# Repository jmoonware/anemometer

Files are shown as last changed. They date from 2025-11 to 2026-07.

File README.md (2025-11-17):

# Anemometer Project 
Code for a WiFi sensor and communicator for a [Davis anemometer](https://www.davisinstruments.com/collections/anemometers/products/anemometer-for-vantage-pro2-vantage-pro).

This project uses a Pico W board [RP2040 Pico W](https://www.waveshare.com/raspberry-pi-pico-w.htm) connected to a [Waveshare Pico-Res Touch 3.5 inch touch LCD display](https://www.waveshare.com/wiki/Pico-ResTouch-LCD-3.5) 

The Pico W is ridiculously powerful for a simple WiFi-connected data logger. It can easily service real-time-ish interrupts while communicating over UDP with some other computer (as well as using the I2C bus.)

The electronics are enclosed in a waterproof box with a transparent lid to see the display, powered by a local 5V/3A wall-adapter.

The layout and circuit for the glue board are also included here. There are provisions for I2C devices, a Davis Anemometer, and a 5V servo motor (such as the MG 996R.) There are also a couple of jumpers that can be configured in "debug mode" where the Pico itself simulates the signals that should come from the anemometer (basically, the wind direction 0-3.3 V analog level, and the wind speed reed switch which produces digital pulses at 0 - ~1kHz.)

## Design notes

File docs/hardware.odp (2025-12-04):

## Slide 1

Hole Template

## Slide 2

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
J 14

J 15

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
A B C D E F G H I J K L M N O P Q R S T U V W X Y Z A B

J1: 1,2,3: 5V, NC, GND (Power In)

J2: 1,2,3: 5V, NC, GND (Power Out to Pico)

J3: 1,2: 3.3V, GND (Power from Pico)

J4: 1,2: SCL, SDA (I2C lines from Pico)

J5: 1,2,3,4: 3.3V, SCL, SDA, GND (I2C Bus)

J6, J7 = J5 (I2C Bus)

J8: 1,2,3,4: 3.3V, DIR, GND, SPD (Anemometer, yellow=1)

J9, J10: 1,2: JA, JB (Jumpers, closed in normal ops)

J11: 1,2,3,4: PA1, AGND, PA0,NC (Pico DIR [blu], AGND[grn],SPD[yel])

J12: 1,2,3: PWMIN, JA,JB (Debug; DBG Bl to 1, Jump 2-3 DIR Pico)

J13: 1,2,3: GND, 5V, PWM, PWMIN (Servo; Pin 4 to Debug Black [Pico Pin 9])

J14: 1 GND

J15: 1 PWM (Black wire from Pico Pin 9/D6)

Debug Mode Notes:

Servo PWMIN (Pico Black Pin 9) to J12-1 for debug DIR mode (add jump J12 2-3)

Debug Speed Mode – Remove J9 jumper, Pico White Pin 6 to J9-1

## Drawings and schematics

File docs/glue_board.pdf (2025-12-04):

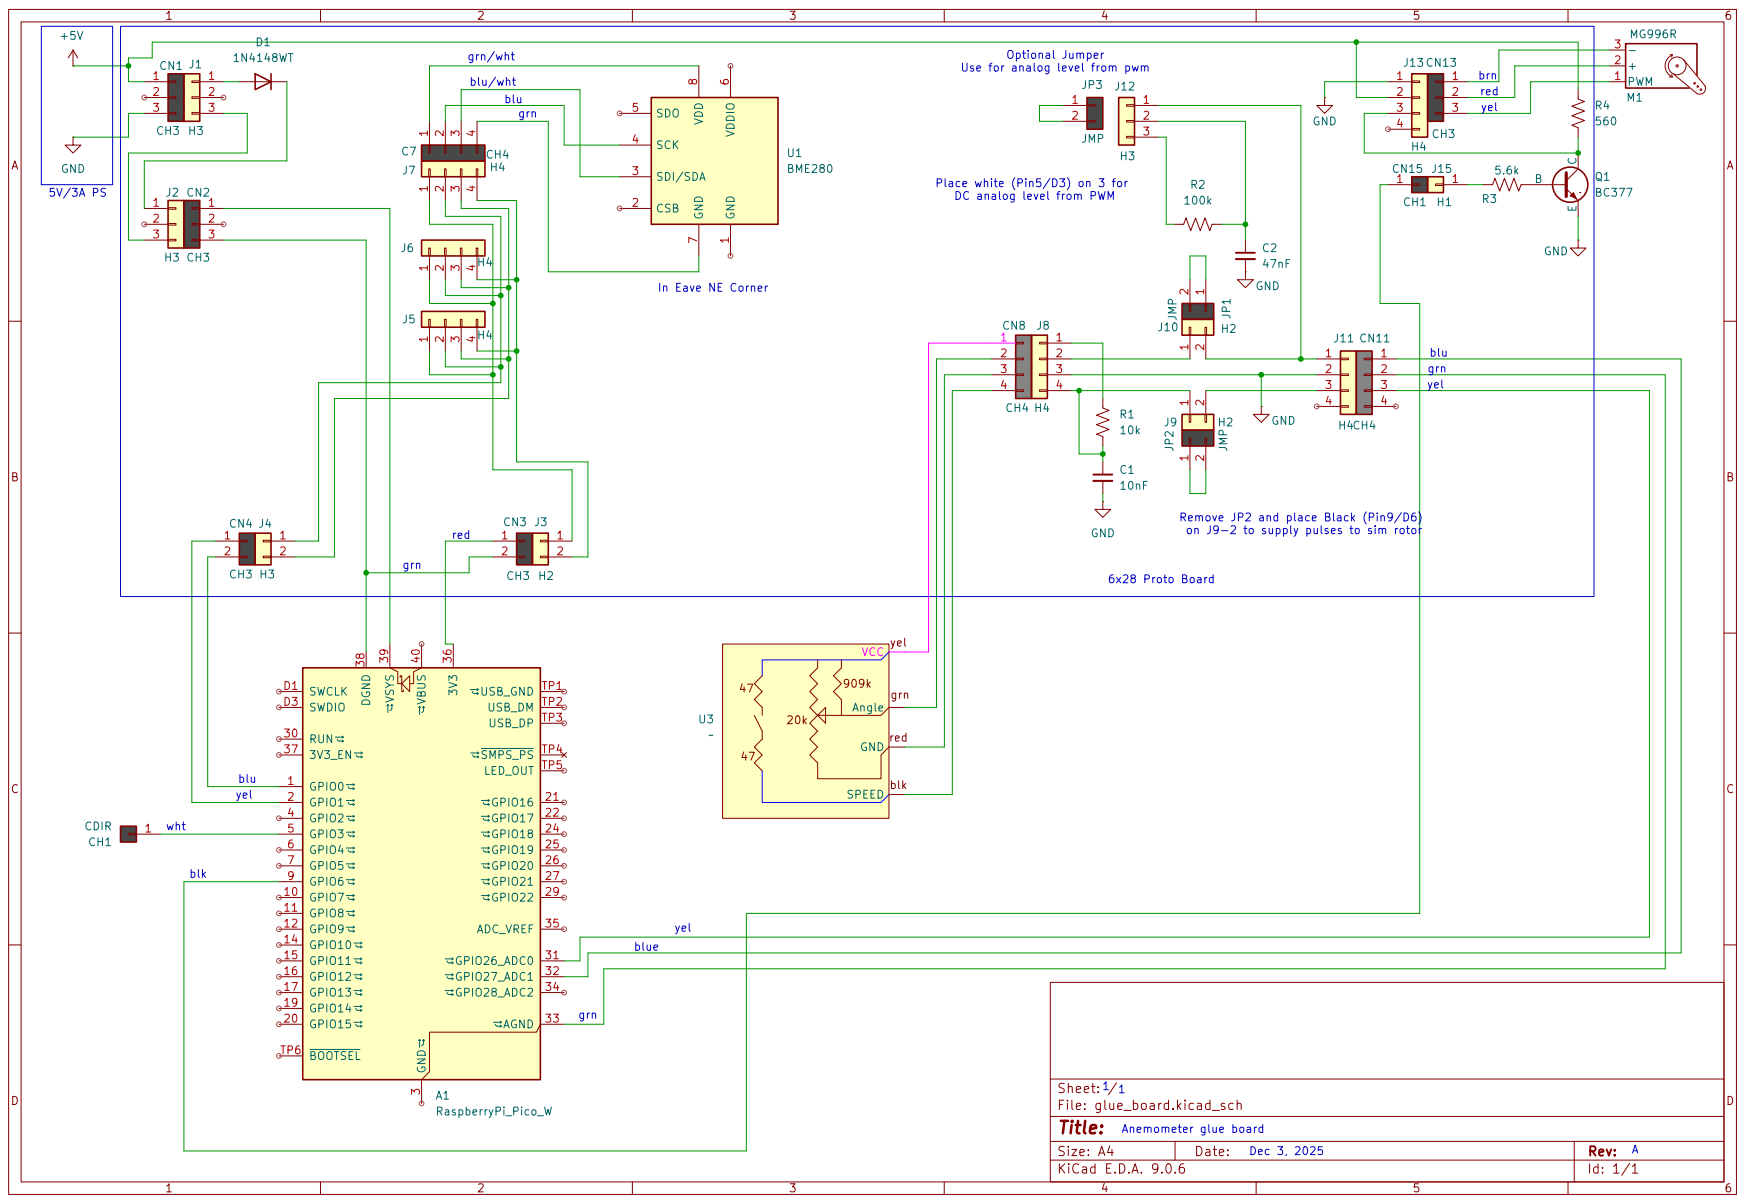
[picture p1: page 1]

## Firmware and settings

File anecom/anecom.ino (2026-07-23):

#include <WiFi.h>
#include <NTPClient.h>
#include <AsyncUDP_RP2040W.h>
#include <Adafruit_BME280.h>
#include <hardware/watchdog.h>

#define WATCHDOG_DELAY_MS 5000

// secret, contains definition of local_ssid, local_pass, and data_url in three lines, literally: 
// char local_ssid[] = "NNN";  //  your network SSID (name)
// char local_pass[] = "PPP";  // your network password
#include "/home/jmoon/Arduino/libraries/local/ssid_harvest.h"
IPAddress static_ip(192,168,1,10);
IPAddress static_dns(192,168,1,2);
IPAddress static_gateway(192,168,1,1);
IPAddress static_subnet(255,255,255,0);

#include <SPI.h>
#include <Adafruit_GFX.h>
#include "Fonts/FreeSerif9pt7b.h"
#include "Fonts/FreeMonoBold9pt7b.h"
#include "Fonts/FreeMonoBold24pt7b.h"
#include "Fonts/FreeMonoBold18pt7b.h"
#include "Fonts/FreeMonoBold12pt7b.h"
#include <TFT_eSPI.h>
#include <hardware/pwm.h>
#include <elapsedMillis.h>

#include <Wire.h>

#include "src/DateTimeNTP/DateTimeNTP.h"
#include "src/windcal.h"

#define VERSION_STRLEN 9
char version[] = "202607221";

// Backlight update = 133 MHz/(255*2360) = 221 Hz
#define BACKLIGHT_DIV 255
#define BACKLIGHT_TOP 2360
TFT_eSPI tft = TFT_eSPI();
uint8_t backlight_pwm_slice;

// here "physical pin" means pins 1-40 of the Pico W board
#define DEBUG_DIR_PWM_PIN D6 // physical pin 9, black wire, also motor PWM
#define DEBUG_SPEED_PWM_PIN D4 // physical pin 6
#define DEBUG_SPEED_ISR_PIN D3 // physical pin 5, white wire
// 133/(522*255) ==> 1.0008 ms per interrupt
#define DEBUG_SPEED_ISR_TOP 522 // clock cycles (possibly pre-divided) to generate IRQ
#define DEBUG_SPEED_ISR_CLK_DIV 255 // pre-divide 133 MHz clock by this
#define DEBUG_DAC_TOP 1024 // clock cycles between pulses
#define DEBUG_DAC_CLK_DIV 1

#define PICOW_CLK_FREQ 133000000
#define MOTOR_TOP 10431 // with 255 clk div is 50 Hz (20 ms period)
#define MOTOR_CLK_DIV 255

// pwm counters used in debug/motor control
uint8_t dirSlice;
uint8_t speedSlice;

// pins for actual sensor
#define WIND_DIR_PIN D27 // A1, physical pin 32
#define WIND_SPEED_PIN D26 // A0, physical pin 31
#define ADC_GROUND 33 // physical pin 33; just listed for reference

// NTP time stuff
WiFiUDP ntpUDP;
NTPClient theNTPUDPClient(ntpUDP);
DateTimeNTP dtntp(&theNTPUDPClient);
#define NTP_RETRIES 3 
int wifi_status = WL_IDLE_STATUS;     // the Wifi radio's status

// UDP stuff
AsyncUDP udp;
#define UDP_LISTEN_PORT 8225
#define INCOMING_UDP_PACKET_SZ 64
unsigned char incoming_packet_buf[INCOMING_UDP_PACKET_SZ];
#define OUTGOING_UDP_PACKET_SZ 64
unsigned char outgoing_packet_buf[OUTGOING_UDP_PACKET_SZ];
#define INCOMING_UDP_PACKET_DATA_SZ 32

elapsedMillis rotor_millis;
elapsedMillis update_millis;
elapsedMillis bme_update_millis;
elapsedMillis wifi_millis = 0;

uint32_t update_delay = 1*1000; // ms, for raw sensor data
uint32_t bme_update_delay = 60*1000; // ms, for BME T/H/P sensor 
uint32_t wifi_update_delay = 60*1000; // ms, for checking if we need to attempt a reconnect

enum GIZMO_STATES {
  STATE_UPDATE,
  STATE_DO_LEFT_BUTTON,
  STATE_DO_RIGHT_BUTTON,
  STATE_MOTOR_MOVING,
  STATE_CHECK_WIFI,
  STATE_WAIT
};
uint8_t gizmo_state;

enum GIZMO_ERRORS {
  ERROR_NONE = 0,
  ERROR_NTP_INIT = 1,
  ERROR_BMEA_INIT = 2,
  ERROR_BMEB_INIT = 4,
  ERROR_WATCHDOG_REBOOT = 8, 
};
static uint16_t gizmo_error_reg = 0;

enum BITMAP_NAMES {
  DATE_CANVAS,
  T_CANVAS,
  H_CANVAS,
  P_CANVAS,
  WINDV_CANVAS,
  WINDA_CANVAS,
  DATA_CANVAS, // general purpose
  NUM_BITMAPS
};

GFXcanvas1 *label_canvases[NUM_BITMAPS]; 
GFXcanvas1 *data_canvases[NUM_BITMAPS]; 
TFT_eSPI_Button left_button = TFT_eSPI_Button();
TFT_eSPI_Button right_button = TFT_eSPI_Button();

#define LABEL_WIDTH 150
#define LABEL_OFFSET 35

int data_pos[][4] = {
  {0,0,320,50}, // x, y, w, h; date
  {LABEL_WIDTH,70,320-LABEL_WIDTH,50}, // temp
  {LABEL_WIDTH,120,320-LABEL_WIDTH,50}, // hum
  {LABEL_WIDTH,170,320-LABEL_WIDTH,50}, // pressure
  {LABEL_WIDTH,220,320-LABEL_WIDTH,50}, // wind v
  {LABEL_WIDTH,270,320-LABEL_WIDTH,50}, // wind angle
  {0,320,320,50}, // data
};

int label_pos[][4] = {
  {0,0,320,50}, // x, y, w, h; date
  {0,70,LABEL_WIDTH,50}, // temp
  {0,120,LABEL_WIDTH,50}, // hum
  {0,170,LABEL_WIDTH,50}, // pressure
  {0,220,LABEL_WIDTH,50}, // wind v
  {0,270,LABEL_WIDTH,50}, // wind angle
  {0,320,320,50}, // data
};

// text color, background color
int label_canvas_colors[][2] = {
  {TFT_SKYBLUE,TFT_BLACK},
  {TFT_GREEN,TFT_DARKGREY},
  {TFT_GREEN,TFT_BLACK},
  {TFT_GREEN,TFT_DARKGREY},
  {TFT_GREEN,TFT_BLACK},
  {TFT_GREEN,TFT_DARKGREY},
  {TFT_GREEN,TFT_BLACK},
};

int data_canvas_colors[][2] = {
  {TFT_SKYBLUE,TFT_BLACK},
  {TFT_WHITE,TFT_DARKGREY},
  {TFT_WHITE,TFT_BLACK},
  {TFT_WHITE,TFT_DARKGREY},
  {TFT_WHITE,TFT_BLACK},
  {TFT_WHITE,TFT_DARKGREY},
  {TFT_WHITE,TFT_BLACK},
};

void initial_screen() {

  tft.fillScreen(TFT_BLACK);
  tft.setTextColor(TFT_GREEN);
  tft.setTextWrap(true);
  tft.setTextSize(1);
  tft.setCursor(0,0);
  tft.println(""); // cursor is at bottom of font
  tft.println("Connected!");
  tft.println("");

  IPAddress ip = WiFi.localIP();
  tft.setTextColor(TFT_WHITE);
  tft.print("IP Address: ");
  tft.setTextColor(TFT_YELLOW);
  tft.println(ip);

  // print MAC address:
  byte mac[6];
  WiFi.macAddress(mac);
  tft.setTextColor(TFT_WHITE);
  tft.print("MAC: ");
  char mac_str[18];
  sprintf(mac_str, "%02X:%02X:%02X:%02X:%02X:%02X", mac[5],mac[4],mac[3],mac[2],mac[1],mac[0]);
  tft.setTextColor(TFT_YELLOW);
  tft.println(mac_str);

}

static uint16_t isr_high_counts = 2;
static uint16_t isr_low_counts = 48;
static uint16_t isr_high;
static uint16_t isr_low;

uint16_t motor_pulses = 50; // 1 s default with 20 ms period

uint16_t pulse_no = 0;
uint16_t last_motor_angle=0;

void pwmIrqHandler() {
  if (pwm_get_irq_status_mask()&(1<<speedSlice)) {
    pwm_clear_irq(speedSlice);
    if (isr_high!=0 && isr_low==0){
      isr_high--;
      digitalWrite(DEBUG_SPEED_ISR_PIN, HIGH); 
      if (isr_high==0) {
        isr_low=isr_low_counts;
      }
    }
    else if (isr_high==0 && isr_low!=0) {
      digitalWrite(DEBUG_SPEED_ISR_PIN, LOW); 
      isr_low--;
      if(isr_low==0) {
        isr_high=isr_high_counts;
      }
    }
    else if ( (isr_high==0 && isr_low==0) || (isr_high!=0 && isr_low !=0)) {
      isr_high=isr_high_counts;
      isr_low=0;
    }
  }
  if (pwm_get_irq_status_mask()&(1<<dirSlice)) {
    pwm_clear_irq(dirSlice);
    if(pulse_no == 0 || pulse_no > motor_pulses) {
      // time to stop
      pwm_set_enabled(dirSlice, false);
      pwm_set_irq_enabled(dirSlice, false);
      digitalWrite(DEBUG_DIR_PWM_PIN, HIGH);
    }
    else pulse_no--;
  }

}




static float last_board_T = -999;

Adafruit_BME280 theBME280; // = Adafruit_BME280();
Adafruit_BME280 theBME280_2; // = Adafruit_BME280();
static float last_bme280_temperature=0;
static float last_bme280_humidity=0;
static float last_bme_280_pressure=0;

static float last_bme280_temperature_2=0;
static float last_bme280_humidity_2=0;
static float last_bme_280_pressure_2=0;

void read_bme280() 
{
  // The BME280 will read the sensors once (storing in registers)
  // then go back to sleep in "forced" mode.
  // Otherwise, it is continuously updating the registers with t_sb delay
  // the Adafruit lib defaults to 250 ms delay, which is enough to heat 
  // the sensor
  if(theBME280.takeForcedMeasurement()) {
    last_bme280_temperature = theBME280.readTemperature();
    last_bme280_humidity = theBME280.readHumidity();
    last_bme_280_pressure = theBME280.readPressure();
  }

  if(theBME280_2.takeForcedMeasurement()) {
    last_bme280_temperature_2 = theBME280_2.readTemperature();
    last_bme280_humidity_2 = theBME280_2.readHumidity();
    last_bme_280_pressure_2 = theBME280_2.readPressure();
  }

}


void read_board_T() {
  last_board_T = analogReadTemp();
}

float vane_offset_angle = 32; // degrees from North
float last_wind_angle = 0;
float wind_angle_breaks[][2] = {
  {0, 22.5}, // N
  {22.5, 67.5}, // NE
  {67.5, 112.5}, // E
  {112.5, 157.5}, // SE
  {157.5, 202.5}, // S
  {202.5, 247.5}, // SW
  {247.5, 292.5}, // W
  {292.5, 337.5}, // NW
  {337.5, 360} // N
};
char wind_angle_labels[][3] = {
  " N",
  "NE",
  " E",
  "SE",
  " S",
  "SW",
  " W",
  "NW",
  " N"
};

char angle_dir[] = "XX";
static int last_vane_reading = 0;

// measure analog voltage
void read_vane() {
  // should be 0-1024 i.e. 10 bit
  last_vane_reading = analogRead(WIND_DIR_PIN); 

  last_wind_angle = ((float)last_vane_reading/1024)*360 + vane_offset_angle;
  if (last_wind_angle > 359.99) {
    last_wind_angle = last_wind_angle - 360;
  }
  else if (last_wind_angle < 0) {
    last_wind_angle = last_wind_angle + 360;
  }

 int widx = -1; 
  for (int i=0; i < 9; ++i) {
    if (last_wind_angle >= wind_angle_breaks[i][0] && last_wind_angle < wind_angle_breaks[i][1]) {
       widx = i;
       break;
     }
  }

   if (widx >= 0) {
     strncpy(angle_dir,wind_angle_labels[widx],2);
   }

}

// this stuff removes outlier values from a small buffer
#define ROTOR_DEBOUNCE_BUFLEN 5
float rotor_debounce_buffer[ROTOR_DEBOUNCE_BUFLEN];
float trim_buffer[ROTOR_DEBOUNCE_BUFLEN];
int debounce_buf_idx=0;

float rotor_mad_frac = 0.0; // maximum abs dev fraction
float last_rotor_trimmed_mean=0;
float last_rotor_trimmed_mad=0;
float rotor_mad_threshold = 0.3;

void timeout_rotor_debounce_buffer() {
  // set to a large value
  for (int i=0; i < ROTOR_DEBOUNCE_BUFLEN; ++i) {
    rotor_debounce_buffer[i]=2e6;
  }
}
// iterative outlier removal
// will converge on median
// assumes positive-definte values 
void calc_trimmed_mean(float *buf,uint8_t n, float *trimmed_mean, float *trimmed_mad, int max_iter=2) {
  // trim highest, lowest and average remaining
  float lowest = buf[0];
  float highest = buf[0];
  int low_idx=0;
  int high_idx=0;

  memcpy(trim_buffer,buf,n*sizeof(float));
  int buflen = n;

  for (int j=0; j < max_iter; ++j) {
    *trimmed_mean = 0;
    *trimmed_mad = 0;
    for (int i=1; i < buflen; ++i) {
      if (trim_buffer[i] < lowest) {
        low_idx=i;
        lowest = trim_buffer[i];
      }
      if (trim_buffer[i] > highest) {
        high_idx=i;
        highest = trim_buffer[i];
      }
    } 
    // all values the same
    if(low_idx==high_idx) {
      *trimmed_mean=trim_buffer[0];
      *trimmed_mad = 0;
      break;
    }
    // compute mean for mad and update trim buffer
    int trim_idx=0;
    for (int i=0; i < buflen; ++i) {
      if (i!=low_idx && i!=high_idx) {
        *trimmed_mean += (float)trim_buffer[i];
        ++trim_idx;
      }
    }
    *trimmed_mean = *trimmed_mean/(buflen-2);

    // compute trimmed MAD
    for (int i=0; i < buflen; ++i) {
      if (i!=low_idx && i!=high_idx) {
        *trimmed_mad += abs((float)trim_buffer[i] - *trimmed_mean);
      }
    } 
    *trimmed_mad = *trimmed_mad/(buflen-2);

    // check to see if we need more iterations
    if (*trimmed_mean > 0) {
      if(*trimmed_mad/ (*trimmed_mean) < rotor_mad_threshold) {
        break;
      }
    }
    else if (*trimmed_mean == 0) {
      break; // only way to get in pos-def values
    }
    // another round of trimming
    // remove low/high vals from trim_buffer
    for(int k=low_idx; k < buflen-1; ++k) {
      trim_buffer[k]=trim_buffer[k+1];
    }
    for(int k=high_idx; k < buflen-1; ++k) {
      trim_buffer[k]=trim_buffer[k+1];
    }

    lowest = trim_buffer[0];
    highest = trim_buffer[0];
    buflen = buflen - 2;
    low_idx = 0;
    high_idx = 0;
  } // j

}

#define DEBOUNCE_US 500

static float last_rotor_interrupt_delta = 0; // elapsed millisecs
static float last_wind_velocity = 0;

volatile float last_rotor_millis = millis();
volatile float rotor_isr_now = millis();
// after rotor_timeout seconds, just set wind velocity to zero
volatile float rotor_timeout = 5000;
volatile unsigned long last_valid_edge_micros = 0;
volatile bool edgeCheckPending = false;

// alarm function to check if the falling edge turned into low signal (not just a glitch) 
int64_t confirmEdgeLow(alarm_id_t id, void *user_data) {
  edgeCheckPending = false;

  // Confirm that the signal is still low after debounce interval
  if (digitalRead(WIND_SPEED_PIN) == LOW) {
    if (rotor_isr_now > last_rotor_millis && last_rotor_millis != 0) {
      last_rotor_interrupt_delta = rotor_isr_now - last_rotor_millis; 
    }
    last_rotor_millis = rotor_isr_now;
  
//    rotor_debounce_buffer[debounce_buf_idx] = last_rotor_interrupt_delta;
//    debounce_buf_idx+=1;
//    if (debounce_buf_idx >= ROTOR_DEBOUNCE_BUFLEN) {
//      debounce_buf_idx = 0; //reset
//    }
//    calc_trimmed_mean(rotor_debounce_buffer, ROTOR_DEBOUNCE_BUFLEN, &last_rotor_trimmed_mean, &last_rotor_trimmed_mad);
// TURN OFF TRIMMED MEAN FOR NOW
    last_rotor_trimmed_mean = last_rotor_interrupt_delta;
    last_rotor_trimmed_mad = 0;
    // the untrimmed latest value
    if (last_rotor_interrupt_delta > 0) {
      last_wind_velocity = ((float)2250)/last_rotor_interrupt_delta;
    }
  }
  return 0;   // one-shot alarm
}

// this is triggered on falling edge of rotor switch
// It sets an alarm later which checks that the signal remains low for at least DEBOUNCE_US
void rotorIsr() {
//    digitalWrite(DEBUG_DIR_PWM_PIN, LOW);

  if (edgeCheckPending) {
    return;   // ignore additional noise while validation is pending
  }

  rotor_isr_now = millis();
  edgeCheckPending = true;
  add_alarm_in_us(DEBOUNCE_US, confirmEdgeLow, NULL, false);
  
//    digitalWrite(DEBUG_DIR_PWM_PIN, HIGH);
}

// initialize I2C
TwoWire theWire(i2c0,D0,D1);

void start_screen() {

  // nothing was coming out of pins from scope so had to do this manually
  gpio_set_function(TFT_CS, GPIO_FUNC_SPI);
  gpio_set_function(TFT_SCLK, GPIO_FUNC_SPI);
  gpio_set_function(TFT_MOSI, GPIO_FUNC_SPI);
  gpio_set_function(TFT_MISO, GPIO_FUNC_SPI);

  tft.init();

  // can use PWM on this pin to dim screen - TODO
  pinMode(TFT_BL, OUTPUT); // GPIO13 = PWM 6B 
  gpio_set_function(TFT_BL, GPIO_FUNC_PWM);
  backlight_pwm_slice = pwm_gpio_to_slice_num(TFT_BL);
  pwm_config backlightConfig = pwm_get_default_config();
  pwm_config_set_wrap(&backlightConfig, BACKLIGHT_TOP); // with 255 prescaling, gets to 220 Hz  
  pwm_init(backlight_pwm_slice, &backlightConfig, true);
  pwm_set_chan_level(backlight_pwm_slice, 1, BACKLIGHT_TOP-1); // initial value
  pwm_set_clkdiv_int_frac(backlight_pwm_slice, BACKLIGHT_DIV, 0); // 133 MHz/255 = 521.6 kHz clock freq

  tft.setRotation(2);
  tft.fillScreen((TFT_BLACK));

  // DO NOT use the Adafruit_GFX fonts! 
  //  tft.setFreeFont(&FreeSerif9pt7b); 
  tft.setTextFont(2);
  tft.setTextSize(2);
//  tft.setCursor(20, 0, 2);
  tft.setTextColor(TFT_SKYBLUE);
  tft.println(" ");
  tft.println("Hello!");
  tft.setTextColor(TFT_GREEN); 
  tft.println("Hello!");
  tft.setTextColor(TFT_RED); 
  tft.println("Hello!");
  tft.setTextColor(TFT_WHITE);
  tft.println("Connecting"); 


}


///////////////////////////////
// Checks if wifi is connected and attempts to reconnect if not
///////////////////////////////
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
void loop() {

  watchdog_update();

  uint16_t x,y;
  if (tft.getTouch(&x, &y)) {
    if (left_button.contains(x,y)) {
      if (!left_button.isPressed()) {
        left_button.press(true); 
        left_button.drawButton(true);
        gizmo_state = STATE_DO_LEFT_BUTTON;
      }
    }
    else if (right_button.contains(x,y)) {
      if (!right_button.isPressed()) {
        right_button.press(true); 
        right_button.drawButton(true);
        gizmo_state = STATE_DO_RIGHT_BUTTON;
      }
    }
    else {
        gizmo_state = STATE_UPDATE;
      }
  }
  else if (pulse_no > 0 && update_millis < update_delay) {
    gizmo_state = STATE_MOTOR_MOVING;
  }
  else if (wifi_millis > wifi_update_delay) {
      gizmo_state = STATE_CHECK_WIFI;
  }
  else if (update_millis > update_delay) {
      gizmo_state = STATE_UPDATE;
      update_millis = 0;
      digitalWrite(PIN_LED, HIGH);
      delay(50);
      digitalWrite(PIN_LED, LOW);
  }
  else {
    gizmo_state = STATE_WAIT;
  }

  switch (gizmo_state) {
    case STATE_CHECK_WIFI:
    {
      wifi_millis = 0;
      // make sure wifi is still connected
      check_wifi();
      break;
    }
    case STATE_UPDATE:
    {
      // update sensor values
      read_board_T();
      read_vane();
      if (bme_update_millis >= bme_update_delay) {
        read_bme280();
        bme_update_millis=0;

        data_canvases[T_CANVAS]->fillScreen(TFT_BLACK);
        data_canvases[T_CANVAS]->setFont(&FreeMonoBold18pt7b);
        data_canvases[T_CANVAS]->setCursor(15, LABEL_OFFSET);
        data_canvases[T_CANVAS]->printf("%.1f" ,(9*last_bme280_temperature/5)+32);

        data_canvases[H_CANVAS]->fillScreen(TFT_BLACK);
        data_canvases[H_CANVAS]->setFont(&FreeMonoBold18pt7b);
        data_canvases[H_CANVAS]->setCursor(15, LABEL_OFFSET);
        data_canvases[H_CANVAS]->printf("%.1f" ,last_bme280_humidity);

        data_canvases[P_CANVAS]->fillScreen(TFT_BLACK);
        data_canvases[P_CANVAS]->setFont(&FreeMonoBold18pt7b);
        data_canvases[P_CANVAS]->setCursor(15, LABEL_OFFSET);
        data_canvases[P_CANVAS]->printf("%.2f",0.001*last_bme_280_pressure/3.387);

        data_canvases[DATA_CANVAS]->fillScreen(TFT_BLACK);

        for (int i=0; i < NUM_BITMAPS; ++i) {
          if(i==T_CANVAS || i== H_CANVAS || i== P_CANVAS || i==DATA_CANVAS) {
            tft.drawBitmap(data_pos[i][0],data_pos[i][1],data_canvases[i]->getBuffer(),data_pos[i][2],data_pos[i][3],data_canvas_colors[i][0],data_canvas_colors[i][1]);
          }
        }

      }


       // update date/time first
      dtntp.get_date();
      data_canvases[DATE_CANVAS]->fillScreen(TFT_BLACK);
      data_canvases[DATE_CANVAS]->setFont(&FreeMonoBold12pt7b);
      data_canvases[DATE_CANVAS]->setCursor(30, 16);
      data_canvases[DATE_CANVAS]->printf("%s\n",dtntp.date_cstring);
      int16_t ycur = data_canvases[DATE_CANVAS]->getCursorY();
      data_canvases[DATE_CANVAS]->setCursor(0, ycur+5);
      data_canvases[DATE_CANVAS]->setFont(&FreeMonoBold18pt7b);
      data_canvases[DATE_CANVAS]->printf("%s",dtntp.time_cstring);

      data_canvases[WINDA_CANVAS]->fillScreen(TFT_BLACK);
      data_canvases[WINDA_CANVAS]->setFont(&FreeMonoBold18pt7b);
      data_canvases[WINDA_CANVAS]->setCursor(5, LABEL_OFFSET);
      data_canvases[WINDA_CANVAS]->printf("%.0f %s",last_wind_angle, angle_dir);

      data_canvases[WINDV_CANVAS]->fillScreen(TFT_BLACK);
      data_canvases[WINDV_CANVAS]->setFont(&FreeMonoBold18pt7b);
      data_canvases[WINDV_CANVAS]->setCursor(5, LABEL_OFFSET);
      // nominal speed is S = 2250/T where T is in ms and S is in mph
      // See e.g.
      // https://www.digitalconcepts.net.au/arduino/index.php?op=DavisWind
      // There is a correction table vs. angle available too: see
      //  https://github.com/kobuki/weewx-meteoRX/tree/master
      float rotor_now = millis();
      if (rotor_now - last_rotor_millis > rotor_timeout) {
        // briefly disable interrupts
//          noInterrupts();
          last_rotor_millis = rotor_now;
          last_rotor_trimmed_mean = 1e6;
          last_rotor_trimmed_mad = 0;
// Comment out MAD outlier code for now
//          timeout_rotor_debounce_buffer();
//        setting to 0 is not right - the next value could be very small and outlier trimming will 
//        provide a perfectly valid very small interrpt time, leading to spurious high velocity readings
//          memset(rotor_debounce_buffer,0,sizeof(float)*ROTOR_DEBOUNCE_BUFLEN);
//          interrupts();
          data_canvases[WINDV_CANVAS]->printf("0.0 *");
      }
      else if (last_rotor_trimmed_mean > 0) {
          if ((last_rotor_trimmed_mad/last_rotor_trimmed_mean) < rotor_mad_threshold) {       
            data_canvases[WINDV_CANVAS]->printf("%.1f", 2250.0/last_rotor_trimmed_mean);
          }
      }
      else {
        data_canvases[WINDV_CANVAS]->printf("0.0");
      }

//      data_canvases[DATA_CANVAS]->fillScreen(TFT_BLACK);
//      data_canvases[DATA_CANVAS]->setFont(&FreeMonoBold12pt7b);
//      data_canvases[DATA_CANVAS]->setCursor(5, 40);
//      data_canvases[DATA_CANVAS]->printf("%.1f %.3f",last_rotor_trimmed_mean, last_rotor_trimmed_mad);

      // only update selected
      for (int i=0; i < NUM_BITMAPS; ++i) {
          if(i==WINDA_CANVAS || i== WINDV_CANVAS || i== DATE_CANVAS) {
            tft.drawBitmap(data_pos[i][0],data_pos[i][1],data_canvases[i]->getBuffer(),data_pos[i][2],data_pos[i][3],data_canvas_colors[i][0],data_canvas_colors[i][1]);
          }
      }

      if (left_button.isPressed()) {
        left_button.press(false);
        left_button.drawButton();
      }
      if (right_button.isPressed()) {
        right_button.press(false);
        right_button.drawButton();
      }

      break;
    }
    case STATE_DO_LEFT_BUTTON: 
    {
      set_motor_position(95);
      break;
    }
    case STATE_DO_RIGHT_BUTTON: 
    {
      set_motor_position(5);
      break;
    }
    case STATE_MOTOR_MOVING: 
    {
      break;
    }
    case STATE_WAIT:
    {
      break;
    }
  }

}

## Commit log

2025-11-09 First check in - connects to WiFi, prints time to TFT screen
2025-11-11 Ack Nack packets work, added static IP, included some error checking for NTP
    [anecom.ino]
2025-11-17 Lots of updates to anecom sketch to provide for debug and motor commands. Needs cleaning up. Also update README to reflect new architecture.
2025-11-17 Fix to reboot NTP problem - WiFi sometimes needs multiple tries for some reason
    [anecom.ino]
2025-11-20 Display looks as needed, servo working
2025-11-20 Fix typo in vel printf statement
    [anecom.ino]
2025-11-20 Working in debug mode, fixed a couple bugs in debug pwm modes
    [anecom.ino]
2025-11-20 Fixed pwm reset between debug and motor control modes
    [anecom.ino]
2025-11-24 added rotor outlier removal, moved away from elapsedMillis for rotor timing, added motor movement code and buttons on screen
2025-11-29 Changed angles for buttons, added correct type and sign parsing for pclient
    [anecom.ino]
2025-12-02 Better handling of low rotor speeds
2025-12-03 Added version to status, fixed small issue with display on low v wind, added string type to pclient
    [anecom.ino]
2025-12-04 Fixed typo in comment, added kicad files for glue board
    [glue_board.kicad_sch]
2025-12-05 Went to forced mode on BME280, and added ability to change temp-humdity-pressure interval with a command
2025-12-09 update to pclient and added device for logging, updated the way BME280 samples and bumped version
    [glue_board.kicad_sch]
2025-12-09 Moved files around
    [glue_board.kicad_sch]
2026-05-27 Added wifi check, debounce callback, last error state command
    [anecom.ino]
2026-06-14 added second BME sensor and reboot command; there is a run time bug in the anemometer wind speed ISR (stops responding to edge trigger after a few days...)
    [anecom.ino]
2026-07-23 updates to version and some screen update logic; MAD code still commented out, using the timer-debounce value directly for rotor interval
